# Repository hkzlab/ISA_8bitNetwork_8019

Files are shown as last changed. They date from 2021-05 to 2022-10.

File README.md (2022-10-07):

# RTL8019AS ISA 8bit Network Card

## Introduction

This is an 8bit reimplementation and repackaging of [Manawyrm's ISA8019](https://github.com/Manawyrm/ISA8019), a NE2000-compatible card for the ISA bus.

Differences from the original version include:
- 8bit only design (significantly more compact than the 16bit version)
- Most of the components are now THT (except EEPROM, Network IC and transformer)

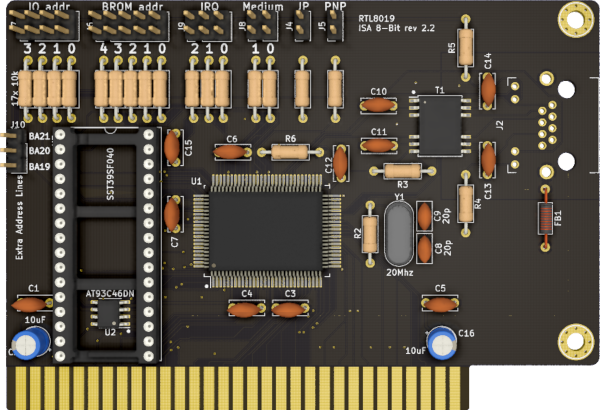
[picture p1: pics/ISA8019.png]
Rev. 2.2 PCB


### Disclaimer

I take NO responsibility for what happens if you decide to build and use this card. Your computer might crash, catch fire or be destroyed in other nasty ways.
Also, as this card is mostly based on the work of others, You're encourauged to take what you deem fit from this, and use it in your projects!

Additionally, do **NOT CONTACT Manawyrm FOR SUPPORT**, while this board is derived from their work, it is not their product, please do not waste their time.

## Configuration

The board can work in 3 modes:
- Jumper mode (JP jumper set)
This mode allows for manual configuration of any parameters (I/O address, IRQ, BROM address & size, etc.) manually via jumpers. Refer to the back of the PCB for details. 
- EEPROM mode (also called "Jumperless", no jumpers set)
In this mode, all parameters can be configured via the RSET8019.EXE dos utility and will be stored in the 9364 I²C EEPROM.
- PnP mode
For modern computers and operating systems like Windows 9x or Linux, this mode is ideal. Resource management will be done by the BIOS or OS.

I use this 8bit variant in **Jumper mode** (hard to find an 8bit machine with PnP support...).

### Programming utilities

- [RSET8019.EXE](software/Programming%20utilities/Rset8019.exe) for DOS, can set EEPROM parameters, also includes diagnostic functions
- [pg8019](software/Programming%20utilities/pg8019) for DOS, can initialize EEPROM, set MAC address, vendor/product IDs 

### Drivers

- [MS-DOS packet drivers, modded for 8-bit XT machines](software/Drivers/Crynwr%20packet%20driver%20-%20modified%20for%208bit%20operation)

### UMB Support

Revisions 2.4 onward support SRAM chips (e.g. AS6C4008) on the boot ROM slot by correctly bridging J11.

```text
J11 setting, ISA edge connector looking DOWN
EPROM
    | .
    | |
    . |
    
SRAM
    . |
    | |
    | .
```

This is not yet tested by me, but is reported working by modifying a previous revision. Reference this [issue](https://github.com/hkzlab/ISA_8bitNetwork_8019/issues/2).

If you wish to use a SRAM chip for UMB support in previous revisions, cut the traces that go to pin 29 and 31 of the boot ROM, and invert them (connect the trace that went to 29 to pin 31, and vice-versa).

The RTL2UMB software can be found in [this](https://forum.vcfed.org/index.php?threads/pc-dos-3-2-for-5150.78476/) thread.

## Bill of Materials

You can use [LCSC](https://lcsc.com) to source most of the ICs.

- U1: RTL8019AS
- U2: AT93C46DN
- T1: 13F-39MNL
- J2: C133529 CKMTW
- Y1: 20Mhz HC49 crystal
- C9, C9: 20pF ceramic capacitor
- C1,C3-7,C12,C15: 100nF ceramic capacitors
- C2, C16: 10uF/25v electrolytic or ceramic capacitors
- C10-14: 1nF ceramic capacitors
- R4,R5: 1k resistors
- R6-22: 10k resistors
- R3: 200ohm resistor
- R2: 1M resistor
- FB1: Ferrite bead
- ISA bracket: Keystone 9202-1, plus screws. This bracket is made for ISA modems, the hole will be slightly wider than an RJ45 socket.

## Known Issues

- Revision 2.3 has only minor changes, but has not yet been tested by me. Reports are welcome.
- I received a report of this board not allowing Sergey's Micro8088 to boot **unless the IRQ6 line is cut** on the network card. I have not been to reproduce this (maybe because I'm using a terminated backplane?), as the builds I completed are working fine on my Micro8088 cards, but be aware in case you incur in the same issue. **Revision 2.3 keeps IRQ lines 6 and 7, but makes them jumperable and by default disconnected**, so if you have that revision, this should no longer be an issue.

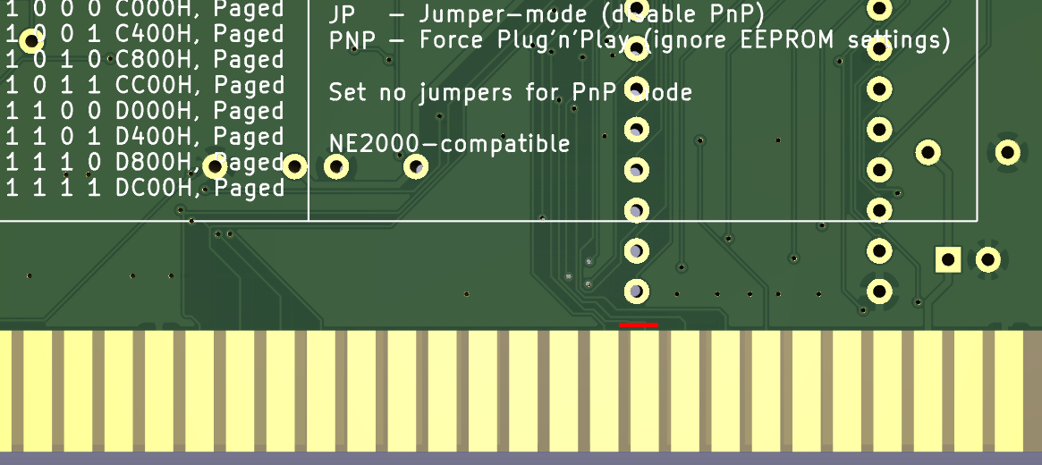
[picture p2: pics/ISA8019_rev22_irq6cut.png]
Rev. 2.2 IRQ6 Trace cut


The picture above shows where to cut to isolate IRQ6 in case you suffer the described issue. The trace is located on the backside of the PCB.

## Credits

- Thanks to [Manawyrm](https://github.com/Manawyrm/ISA8019) for the original project

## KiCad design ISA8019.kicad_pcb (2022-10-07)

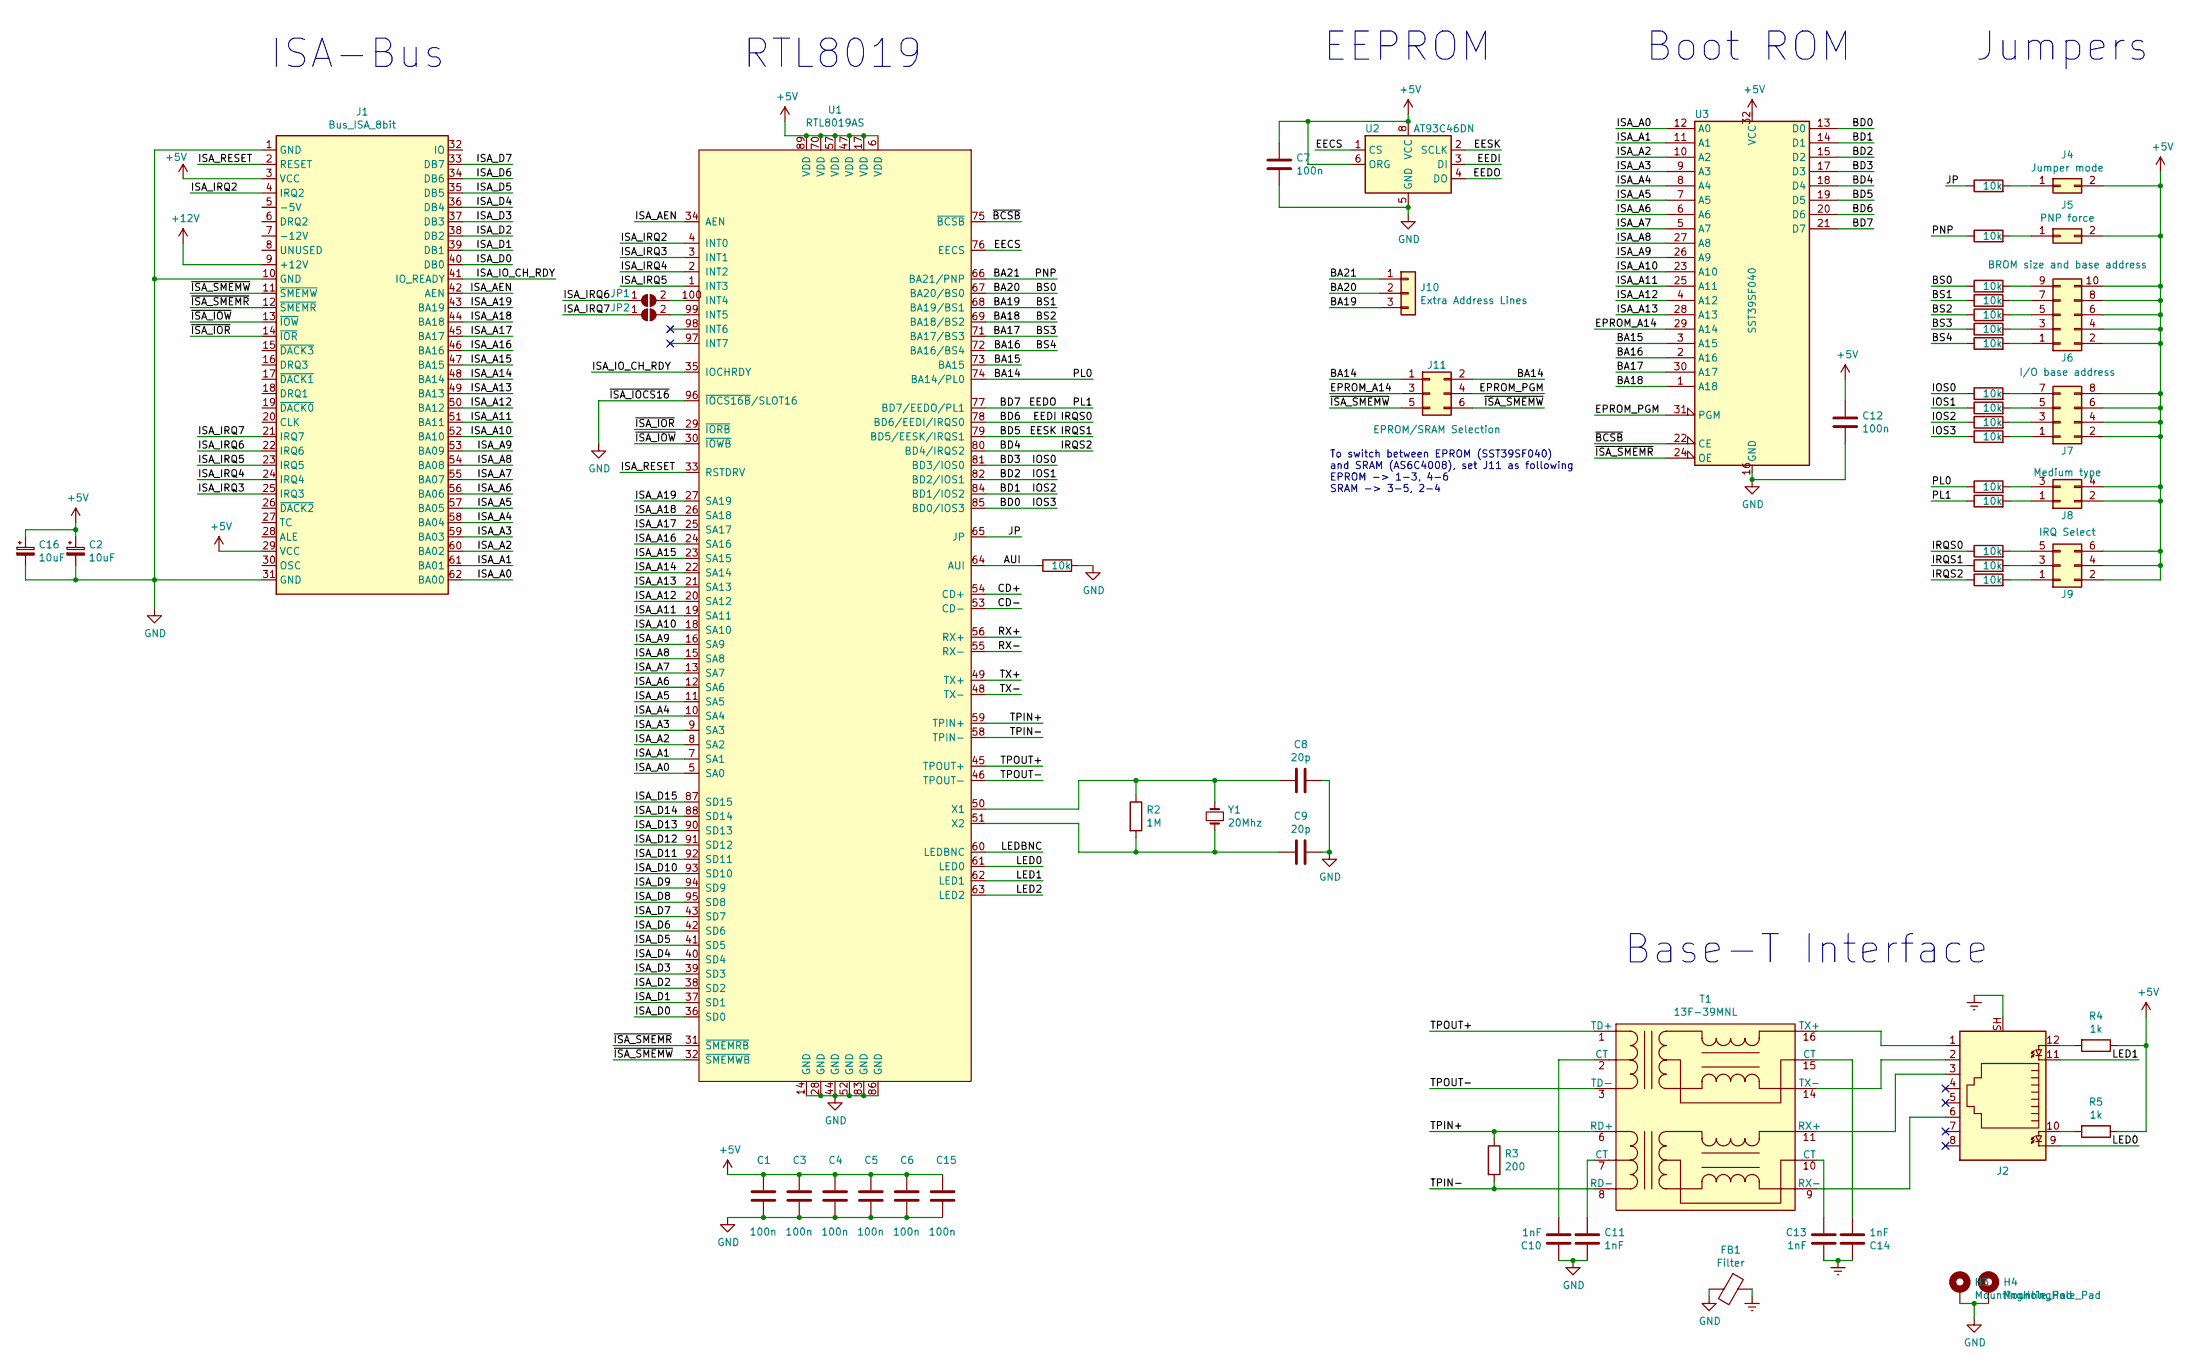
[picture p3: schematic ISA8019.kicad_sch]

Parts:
C1, C3, C4, C5, C6, C7, C12, C15: 100n; C_Disc_D6.0mm_W2.5mm_P5.00mm
C2, C16: 10uF; CP_Radial_D5.0mm_P2.50mm
C8: 20p; C_Disc_D5.0mm_W2.5mm_P2.50mm
C9: 20p; C_Disc_D5.0mm_W2.5mm_P2.50mm; LCSC C1554
C10, C11, C13, C14: 1nF; C_Disc_D6.0mm_W2.5mm_P5.00mm
FB1: Filter; L_Axial_L5.3mm_D2.2mm_P10.16mm_Horizontal_Vishay_IM-1; LCSC C1017
H3, H4: MountingHole_Pad; MountingHole_3.2mm_M3_Pad_Via
J1: Bus_ISA_8bit; Conn_Edge_PCB_ISA8
J2: 8P8C_Shielded; 8P8C_yellow_green_Ckmtw_C133529
J4: Jumper mode; PinHeader_2x01_P2.54mm_Vertical
J5: PNP force; PinHeader_2x01_P2.54mm_Vertical
J6: BROM size and base address; PinHeader_2x05_P2.54mm_Vertical
J7: I/O base address; PinHeader_2x04_P2.54mm_Vertical
J8: Medium type; PinHeader_2x02_P2.54mm_Vertical
J9: IRQ Select; PinHeader_2x03_P2.54mm_Vertical
J10: Extra Address Lines; PinHeader_1x03_P2.54mm_Vertical
J11: EPROM/SRAM Selection; PinHeader_2x03_P2.54mm_Vertical
JP1, JP2: IRQ6_Jumper; SolderJumper-2_P1.3mm_Open_RoundedPad1.0x1.5mm
R2: 1M; R_Axial_DIN0207_L6.3mm_D2.5mm_P10.16mm_Horizontal
R3: 200; R_Axial_DIN0207_L6.3mm_D2.5mm_P10.16mm_Horizontal
R4, R5: 1k; R_Axial_DIN0207_L6.3mm_D2.5mm_P10.16mm_Horizontal
R6, R7, R8, R9, R10, R11, R12, R13, R14, R15, R16, R17, R18, R19, R20, R21, R22: 10k; R_Axial_DIN0207_L6.3mm_D2.5mm_P10.16mm_Horizontal
T1: 13F-39MNL; SOIC-16W-12_7.5x10.3mm_P1.27mm; LCSC C115949
U1: RTL8019AS; LQFP-14x20mm_P0.5mm; LCSC C10016
U2: AT93C46DN; SOIC-8_3.9x4.9mm_P1.27mm; LCSC C6499
U3: SST39SF040; DIP-32_W15.24mm_Socket
Y1: 20Mhz; Crystal_HC49-4H_Vertical

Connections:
+5V: C1.1, C2.1, C3.1, C4.1, C5.1, C6.1, C7.1, C12.1, C15.1, C16.1, J1.3 (VCC), J1.29 (VCC), J4.2, J5.2, J6.2, J6.4, J6.6, J6.8, J6.10, J7.2, J7.4, J7.6, J7.8, J8.2, J8.4, J9.2, J9.4, J9.6, R4.1, R5.1, U1.6 (VDD), U1.17 (VDD), U1.47 (VDD), U1.57 (VDD), U1.70 (VDD), U1.89 (VDD), U2.6 (ORG), U2.8 (VCC), U3.32 (VCC)
+12V: J1.9 (+12V)
/AUI: R6.1, U1.64 (AUI)
/BA14: J11.1, J11.2, R18.1, U1.74 (BA14/PL0)
/BA15: U1.73 (BA15), U3.3 (A15)
/BA16: R13.1, U1.72 (BA16/BS4), U3.2 (A16)
/BA17: R12.1, U1.71 (BA17/BS3), U3.30 (A17)
/BA18: R11.1, U1.69 (BA18/BS2), U3.1 (A18)
/BA19: J10.3, R10.1, U1.68 (BA19/BS1)
/BA20: J10.2, R9.1, U1.67 (BA20/BS0)
/BA21: J10.1, R8.1, U1.66 (BA21/PNP)
/BD0: R17.1, U1.85 (BD0/IOS3), U3.13 (D0)
/BD1: R16.1, U1.84 (BD1/IOS2), U3.14 (D1)
/BD2: R15.1, U1.82 (BD2/IOS1), U3.15 (D2)
/BD3: R14.1, U1.81 (BD3/IOS0), U3.17 (D3)
/BD4: R22.1, U1.80 (BD4/IRQS2), U3.18 (D4)
/BD5: R21.1, U1.79 (BD5/EESK/IRQS1), U2.2 (SCLK), U3.19 (D5)
/BD6: R20.1, U1.78 (BD6/EEDI/IRQS0), U2.3 (DI), U3.20 (D6)
/BD7: R19.1, U1.77 (BD7/EEDO/PL1), U2.4 (DO), U3.21 (D7)
/CD+: U1.54 (CD+)
/CD-: U1.53 (CD-)
/EECS: U1.76 (EECS), U2.1 (CS)
/EPROM_A14: J11.3, U3.29 (A14)
/EPROM_PGM: J11.4, U3.31 (PGM)
/ISA_A0: J1.62 (BA00), U1.5 (SA0), U3.12 (A0)
/ISA_A1: J1.61 (BA01), U1.7 (SA1), U3.11 (A1)
/ISA_A2: J1.60 (BA02), U1.8 (SA2), U3.10 (A2)
/ISA_A3: J1.59 (BA03), U1.9 (SA3), U3.9 (A3)
/ISA_A4: J1.58 (BA04), U1.10 (SA4), U3.8 (A4)
/ISA_A5: J1.57 (BA05), U1.11 (SA5), U3.7 (A5)
/ISA_A6: J1.56 (BA06), U1.12 (SA6), U3.6 (A6)
/ISA_A7: J1.55 (BA07), U1.13 (SA7), U3.5 (A7)
/ISA_A8: J1.54 (BA08), U1.15 (SA8), U3.27 (A8)
/ISA_A9: J1.53 (BA09), U1.16 (SA9), U3.26 (A9)
/ISA_A10: J1.52 (BA10), U1.18 (SA10), U3.23 (A10)
/ISA_A11: J1.51 (BA11), U1.19 (SA11), U3.25 (A11)
/ISA_A12: J1.50 (BA12), U1.20 (SA12), U3.4 (A12)
/ISA_A13: J1.49 (BA13), U1.21 (SA13), U3.28 (A13)
/ISA_A14: J1.48 (BA14), U1.22 (SA14)
/ISA_A15: J1.47 (BA15), U1.23 (SA15)
/ISA_A16: J1.46 (BA16), U1.24 (SA16)
/ISA_A17: J1.45 (BA17), U1.25 (SA17)
/ISA_A18: J1.44 (BA18), U1.26 (SA18)
/ISA_A19: J1.43 (BA19), U1.27 (SA19)
/ISA_AEN: J1.42 (AEN), U1.34 (AEN)
/ISA_D0: J1.40 (DB0), U1.36 (SD0)
/ISA_D1: J1.39 (DB1), U1.37 (SD1)
/ISA_D2: J1.38 (DB2), U1.38 (SD2)
/ISA_D3: J1.37 (DB3), U1.39 (SD3)
/ISA_D4: J1.36 (DB4), U1.40 (SD4)
/ISA_D5: J1.35 (DB5), U1.41 (SD5)
/ISA_D6: J1.34 (DB6), U1.42 (SD6)
/ISA_D7: J1.33 (DB7), U1.43 (SD7)
/ISA_D8: U1.95 (SD8)
/ISA_D9: U1.94 (SD9)
/ISA_D10: U1.93 (SD10)
/ISA_D11: U1.92 (SD11)
/ISA_D12: U1.91 (SD12)
/ISA_D13: U1.90 (SD13)
/ISA_D14: U1.88 (SD14)
/ISA_D15: U1.87 (SD15)
/ISA_IO_CH_RDY: J1.41 (IO_READY), U1.35 (IOCHRDY)
/ISA_IRQ2: J1.4 (IRQ2), U1.4 (INT0)
/ISA_IRQ3: J1.25 (IRQ3), U1.3 (INT1)
/ISA_IRQ4: J1.24 (IRQ4), U1.2 (INT2)
/ISA_IRQ5: J1.23 (IRQ5), U1.1 (INT3)
/ISA_IRQ6: J1.22 (IRQ6), JP1.1 (A)
/ISA_IRQ7: J1.21 (IRQ7), JP2.1 (A)
/ISA_RESET: J1.2 (RESET), U1.33 (RSTDRV)
/JP: R7.1, U1.65 (JP)
/LED0: J2.9, U1.61 (LED0)
/LED1: J2.11, U1.62 (LED1)
/LED2: U1.63 (LED2)
/LEDBNC: U1.60 (LEDBNC)
/RX+: U1.56 (RX+)
/RX-: U1.55 (RX-)
/TPIN+: R3.1, T1.6 (RD+), U1.59 (TPIN+)
/TPIN-: R3.2, T1.8 (RD-), U1.58 (TPIN-)
/TPOUT+: T1.1 (TD+), U1.45 (TPOUT+)
/TPOUT-: T1.3 (TD-), U1.46 (TPOUT-)
/TX+: U1.49 (TX+)
/TX-: U1.48 (TX-)
/~BCSB: U1.75 (~BCSB), U3.22 (CE)
/~ISA_IOR: J1.14 (~IOR), U1.29 (~IORB)
/~ISA_IOW: J1.13 (~IOW), U1.30 (~IOWB)
/~ISA_SMEMR: J1.12 (~SMEMR), U1.31 (~SMEMRB), U3.24 (OE)
/~ISA_SMEMW: J1.11 (~SMEMW), J11.5, J11.6, U1.32 (~SMEMWB)
Earth: C13.2, C14.1, FB1.1, J2.SH
GND: C1.2, C2.2, C3.2, C4.2, C5.2, C6.2, C7.2, C8.1, C9.1, C10.1, C11.2, C12.2, C15.2, C16.2, FB1.2, H3.1, H4.1, J1.1 (GND), J1.10 (GND), J1.31 (GND), R6.2, U1.14 (GND), U1.28 (GND), U1.44 (GND), U1.52 (GND), U1.83 (GND), U1.86 (GND), U1.96 (~IOCS16B/SLOT16), U2.5 (GND), U3.16 (GND)
unnamed: C8.2, R2.1, U1.50 (X1), Y1.2
unnamed: C9.2, R2.2, U1.51 (X2), Y1.1
unnamed: C10.2, T1.2 (CT)
unnamed: C11.1, T1.7 (CT)
unnamed: C13.1, T1.10 (CT)
unnamed: C14.2, T1.15 (CT)
unnamed: J2.1, T1.16 (TX+)
unnamed: J2.2, T1.14 (TX-)
unnamed: J2.3, T1.11 (RX+)
unnamed: J2.6, T1.9 (RX-)
unnamed: J2.10, R5.2
unnamed: J2.12, R4.2
unnamed: J4.1, R7.2
unnamed: J5.1, R8.2
unnamed: J6.1, R13.2
unnamed: J6.3, R12.2
unnamed: J6.5, R11.2
unnamed: J6.7, R10.2
unnamed: J6.9, R9.2
unnamed: J7.1, R17.2
unnamed: J7.3, R16.2
unnamed: J7.5, R15.2
unnamed: J7.7, R14.2
unnamed: J8.1, R19.2
unnamed: J8.3, R18.2
unnamed: J9.1, R22.2
unnamed: J9.3, R21.2
unnamed: J9.5, R20.2
unnamed: JP1.2 (B), U1.100 (INT4)
unnamed: JP2.2 (B), U1.99 (INT5)

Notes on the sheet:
Jumpers
ISA-Bus
Boot ROM
RTL8019
To switch between EPROM (SST39SF040) and SRAM (AS6C4008), set J11 as following EPROM -> 1-3, 4-6 SRAM -> 3-5, 2-4
Base-T Interface
EEPROM

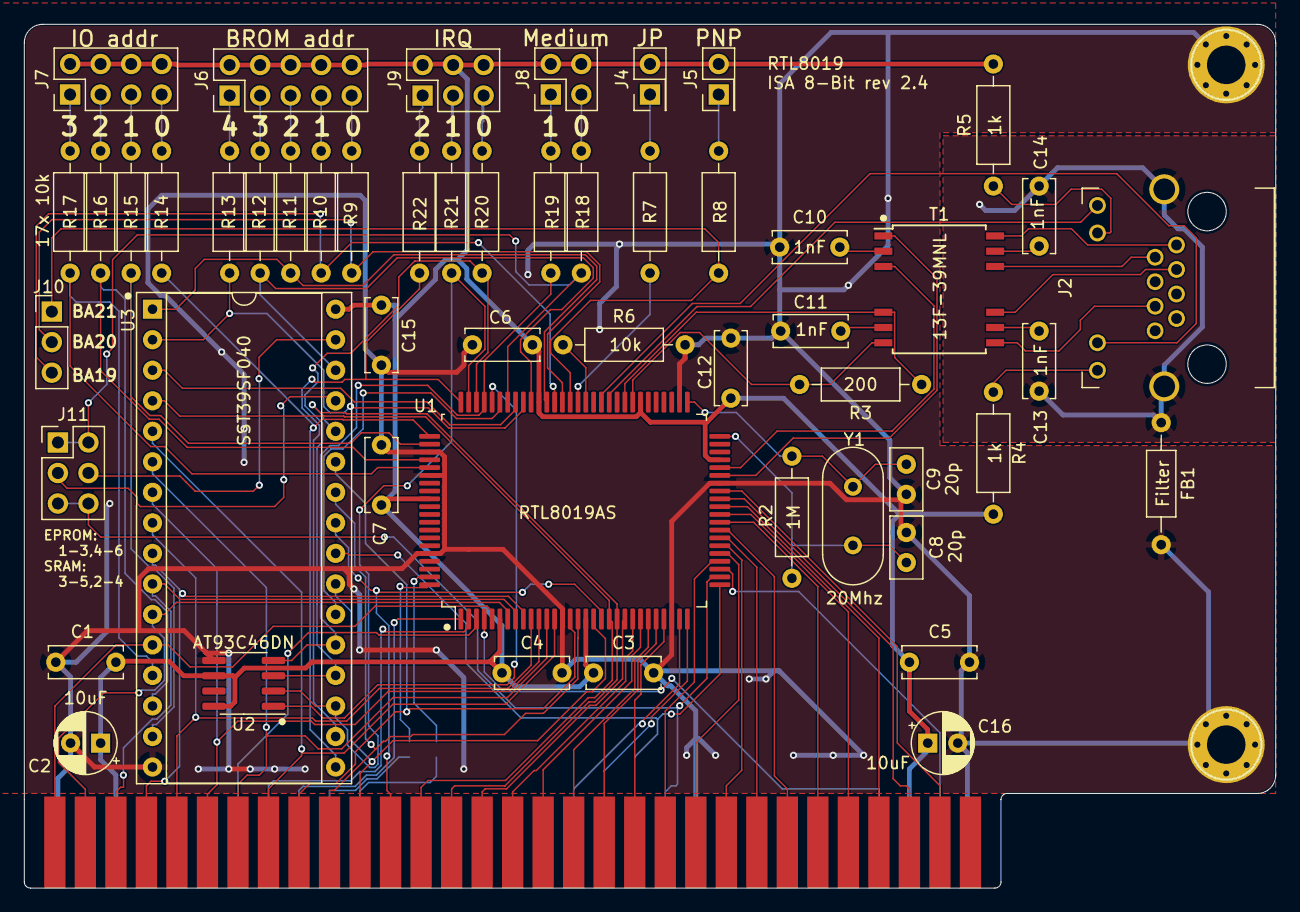
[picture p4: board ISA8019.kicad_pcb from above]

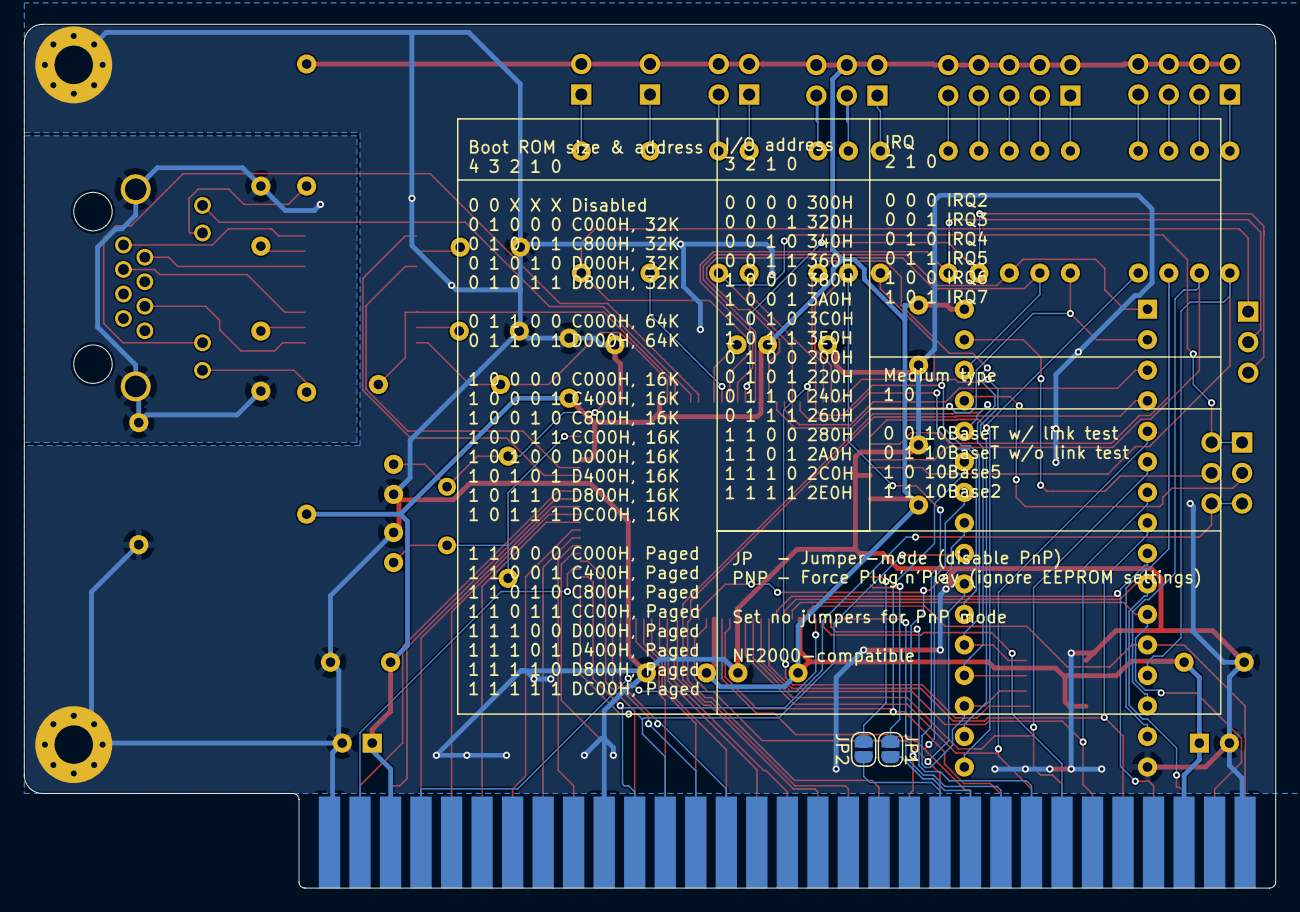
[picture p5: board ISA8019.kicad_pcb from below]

Board: 2 copper layers, 104.1 x 71.9 mm, 57 parts (2 on the bottom side), 102 nets.

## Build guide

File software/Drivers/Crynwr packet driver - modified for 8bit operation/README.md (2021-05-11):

This driver was modified to work with 8bit ISA computers by profdc9.   
  
Source:  
http://www.vcfed.org/forum/showthread.php?41081-NE2000-Packet-drivers-for-8-bit-slots

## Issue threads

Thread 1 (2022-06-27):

Unable to run the card on micro_8088

andykarpov, 2022-06-27:
The card somehow does not allow to start a BIOS on the micro_8088.
I've tried different jumper mode combinations of addresses, irqs, etc - didn't help.
I guess something wrong goes on the data bus, probably.
Did you tested on micro_8088 ?
Does there some tricks may be to start it ?

andykarpov, 2022-06-27:
BTW, the 8019as datasheet says that pin 96 should be pulled down via 27kOhm resistor, because on start it acts as input to sence 8/16 bit slot mode, but after acts as output (open collector). Could it be a problem ?

hkzlab, 2022-06-27:
@andykarpov yup. Not only I tested it there, but I use it there. It's installed in my micro8088 unit, works just fine. I built 3 in total, all worked on that machine, at all the possible processor speeds.

The only thing I did NOT do there is flashing the card, which I did on a 286 machine.

Two things:

- I've ran into a few machines that did NOT like the card (and it's ancestor I took the schematic from, https://github.com/Manawyrm/ISA8019), but the effect was that the interrupts were not registered, the machines still worked fine.
- My micro8088 units (I have more than one) have all their slots occupied (7 board total) plus a passive terminator mounted on the underside of the backplane.

hkzlab, 2022-06-27:
> BTW, the 8019as datasheet says that pin 96 should be pulled down via 27kOhm resistor, because on start it acts as input to sence 8/16 bit slot mode, but after acts as output (open collector). Could it be a problem ?

Can't see why.

- It's either floating or pulled low, so no risk of shorting
- We're not doing 16bit transfers here anyway...

andykarpov, 2022-06-27:
Thanks for the info and explanations, will try to play with the board.
Something goes wrong somewhere :)

Another question - does the 10k pullups for the jumpers are critical ? My board has 12k pullups instead of 10k.
The documentation says that there are 100k pulldowns inside the chip to detect the jumpers settings.
Also, does the board should start without the eeprom ?
I've already tried with and without - still no luck.

BTW, does the ISA bus terminators are necessary for this project? Does they improve something ? Could you please point me the right directions ? :)

hkzlab, 2022-06-27:
> does the 10k pullups for the jumpers are critical ? My board has 12k pullups instead of 10k
Absolutely shouldn't be an issue. There is a lot of leeway there.

> Also, does the board should start without the eeprom ?
Which EEPROM?
The big DIP one? Yup, that is entirely optional. I'm not using it in the board I have in use currently.

The small AT94C46? Nope you need that. And you need that thing programmed to work. See instructions here: https://github.com/Manawyrm/ISA8019
As I mentioned previously, I did not try to plug it unprogrammed in the micro 8088, as I used another machine to program the cards. Have you anything else with an ISA bus to plug it in and try to program it?

> BTW, does the ISA bus terminators are necessary for this project? Does they improve something ? Could you please point me the right directions ? :)
No, not necessary. They are useful once you have many cards on the bus and you start getting interference, which generally leads to instability, especially at high clock speeds. There are active terminators, passive terminators, some backplanes even have them builtin (simple resistor dividers on the lines)...

Can't help much more than this though, certainly can't do remote troubleshooting, as, in the last year, my hobby-time has grown (or should I say shriveled?) very, very thin.

andykarpov, 2022-06-27:
Thank you very much, @hkzlab, will try to follow the instructions from the ISA8019 project to program 93C46 eeprom :)
I guess that is the problem.

andykarpov, 2022-07-01:
Found an issue on the PCB:
The line **ISA_IRQ6** should be disconnected from the chip to work on the **micro_8088** project normally.
After cutting the trace everything goes normally.
BTW, just comparing your schematics with the @skiselev - found that his design using less IRQ lines.

hkzlab, 2022-07-01:
@andykarpov this does not explain why my board work with the micro8088 with the IRQ6 line in place, and I have tried multiple micro8088 builds with multiple builds of this card...
Is this happening even if you configure the card to use jumpers and set it to use something between 2 and 5?

Have a look at the datasheet at page 19: "All unselected interrupt lines will be tri-stated". The line connected to IRQ6 should be disconnected if the board is configured as above.

I can only see a possibility here: you have a solder speck/bridge on the IRQ6 pin of the RTL8019 chip (pin 100) and is firing an interrupt when it should not. Or maybe a faulty chip in respect to that line, which is not tristating the interrupt line correctly. If you have the instrumentation you could try probing that line and see if there is activity when it should be just floating.

That said, I think I will do the following, to stay on the safe side:

1. Mention this incident in the README
2. Maybe add jumpers to disconnect IRQs 6,7,12,15

andykarpov, 2022-07-01:
@hkzlab , well, no ideas what's going on on the IRQ6/7 lines when powering up the board. Probably it interfered somehow with the system before it actually starts and reads the jumper settings, no ideas yet. Good point to see what's happen there with the oscilloscope, will try to do that.

BTW, the problem seems reproducible not only with my board, but also on my friend's board. Chips are from the different batches as well.

How to explain that your boards are working fine with the micro_8088 - well, may be bad soldering somewhere in between pin 99-100 ? :))) You told that you have a few problematic boards - just try to up their 99 and 100 pins and see if it helps or not.

There are no solder bridges on any pins on my board, i've inspected everything with the multimeter and glasses. Bad RTL8019 chip - may be, but finally it just works :)

Anyway, thanks a lot for your help and support!

hkzlab, 2022-07-01:
@andykarpov nah, the other motherboards which had issues with this board (which were not causing the board not to boot, just the IRQs were ignored) were also tested with the original Manawyrm board, which has IRQ6 and 6 disconnected, and showed the same issue.

As it happens on your friend's board too, then I'm beginning to suspect that the lines, even though tri-stated, are picking up noise (by the board itself maybe), and I'm not seeing this issue because my backplane has termination resistors that reduce noise a bit.
That said, better safe than sorry: uploaded revision 2.3 of the board that makes the lines disconnected by default and jumperable if needed, also added the warning on the README.

Let me know how the probing goes!

hkzlab, 2022-07-01:
In the meantime, closing this as it was solved with a hardware hack that is now included in a new board revision.

Closed 2022-07-01.

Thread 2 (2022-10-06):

UMB support

Maxx1234, 2022-10-06:
Hello!

After browsing through this thread: https://forum.vcfed.org/index.php?threads/pc-dos-3-2-for-5150.78476/
I found that this card is capable of supporting SRAM chips (after crosswiring pins 29 & 31) and can actually provide UMBs when using the RTL2UMB utility.

Successfully tested and stable on my Juko ST-12 (ROM setting: 64K @ D000-E000, Chip: AS6C4008-55PCN, crosswired pins 29 & 31).

As VCFED user Eudimorphodon recommended, a new board revision supporting jumper selection between FLASH and SRAM chips would be very interesting.

Thank you for your interesting projects!

Best regards,
Dionisios

hkzlab, 2022-10-07:
Well, this is interesting, thanks for letting me know.
It's surely worth the small change!

hkzlab, 2022-10-07:
Change implemented, revision 2.4 up. I can't currently make a run of it, so if you know anyone that does and tests it, let me know :-)

Maxx1234, 2022-10-08:
Unfortunately I have run out of RTL8019AS (and built enough rev 2.2 boards to cover my current and future needs).  Sorry :( ...
Of course, if I ever build a new board, I will definitely test the current revision and report back.
Thanks anyway!

hkzlab, 2022-10-08:
Ah no worries, I'm in the same situation!
Should You try, let me know!

Closed 2022-10-07.

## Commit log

2021-03-26 import project
    [ISA8019.kicad_pcb, ISA8019.sch]
2021-03-26 8 bit network card variant
    [ISA8019.kicad_pcb, ISA8019.sch]
2021-03-27 Redraw 8 bit board
    [ISA8019.kicad_pcb, ISA8019.sch]
2021-03-27 cleanup board a bit
    [ISA8019.kicad_pcb, ISA8019.sch]
2021-03-27 Update board
    [ISA8019.kicad_pcb]
2021-03-27 Fix top zone fill
    [ISA8019.kicad_pcb]
2021-03-27 Rev 1 gerbers
    [ISA8019.kicad_pcb]
2021-04-17 Fix bottom no-net fill
    [ISA8019.kicad_pcb]
2021-04-17 Add another filter cap
    [ISA8019.kicad_pcb, ISA8019.sch]
2021-04-17 Adjust board edges
    [ISA8019.kicad_pcb]
2021-04-17 Update the revision
    [ISA8019.kicad_pcb]
2021-04-17 Resize board and remove jumper for 16-bit IRQs
    [ISA8019.kicad_pcb, ISA8019.sch]
2021-04-17 Removed useless pulldown resistor
    [ISA8019.kicad_pcb, ISA8019.sch]
2021-04-17 Smaller version of the ethernet card
    [ISA8019.kicad_pcb, ISA8019.sch]
2021-04-17 Redraw fill areas
    [ISA8019.kicad_pcb]
2021-04-17 Silkscreen adjustments
    [ISA8019.kicad_pcb]
2021-04-17 Reorganize zones on the PCB
    [ISA8019.kicad_pcb]
2021-04-24 Added more IRQ options
    [ISA8019.kicad_pcb, ISA8019.sch]
2021-04-24 Cleanup tracks
    [ISA8019.kicad_pcb]
2021-04-25 Tweak ground plane a bit
    [ISA8019.kicad_pcb]
2021-04-27 Add rev 2 gerber
    [ISA8019.kicad_pcb]
2021-05-11 Upload basic software from Manawyrm's repo
    [8019.cfg, 8019as.cfg]
2021-05-12 Remove rev.1 gerbers
2021-05-25 Add keystone bracket
2021-05-25 Add bracket
    [ISA8019.kicad_pcb]
2021-05-25 move pcb on sheet
    [ISA8019.kicad_pcb]
2021-05-25 Slightly move bracket holes for better bracket positioning
    [ISA8019.kicad_pcb]
2021-05-25 Move net connector slightly forward
    [ISA8019.kicad_pcb]
2021-05-25 Move mask zone
    [ISA8019.kicad_pcb]
2021-05-25 Add gerbers for 2.1
    [ISA8019.kicad_pcb]
2021-06-02 Add rev 2.2, supporting an 30SF040 EPROM, also additional address lines are now broken out
    [ISA8019.kicad_pcb, ISA8019.sch]
2021-06-02 Fix address BA14/16 ordering to SST39SF040
    [ISA8019.kicad_pcb, ISA8019.sch]
2021-06-02 Regenerate gerbers
2021-11-09 Update kicad url
2022-07-01 Add revision 2.3 of the board to jumper IRQ6 and 7 and keep them disconnected by default
    [ISA8019.kicad_pcb, ISA8019.kicad_sch]
2022-10-07 Add header to switch between SRAM and EPROM
    [ISA8019.kicad_sch]
2022-10-07 Add some descriptive text for J11
    [ISA8019.kicad_sch]
2022-10-07 Prepare what will be revision 2.4
    [ISA8019.kicad_pcb, ISA8019.kicad_sch]
2022-10-07 Add Revision 2.4
    [ISA8019.kicad_pcb]
